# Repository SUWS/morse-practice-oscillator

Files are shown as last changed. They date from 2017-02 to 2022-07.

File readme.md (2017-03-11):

# Morse Code Practice oscillator

This contains the hardware and firmware designs for a morse code practice oscillator.

## Features

* 9v Battery or 12vDC powered
* Headphone or internal speaker output
* Adjustable Tone and Volume
* Support for paddle keys with variable speed and weight
* Capacitive iambic key unit included on PCB

## Sources and links

* Audio path based on designs by [Forrest Cook (WB0RIO)](http://www.solorb.com/elect/hamcirc/sidetone/)
* Capacitive Iambic key uses circuit from [John Parfrey (M0UKD)](https://m0ukd.com/homebrew/capacitive-cw-touch-key-circuits/)
* Project uses CC By icons from Dave Gandy (power icon (also remixed to make the dial and jack labels)) and Hanan (headphone icon)

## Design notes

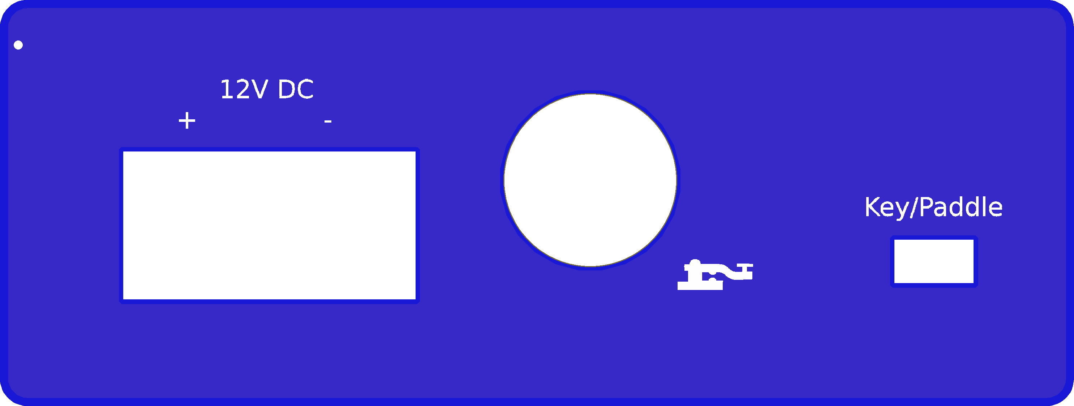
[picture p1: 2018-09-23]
Mechanicial/Sounder/textures/sounder_rear_pp_panel_r2.0_rear.png

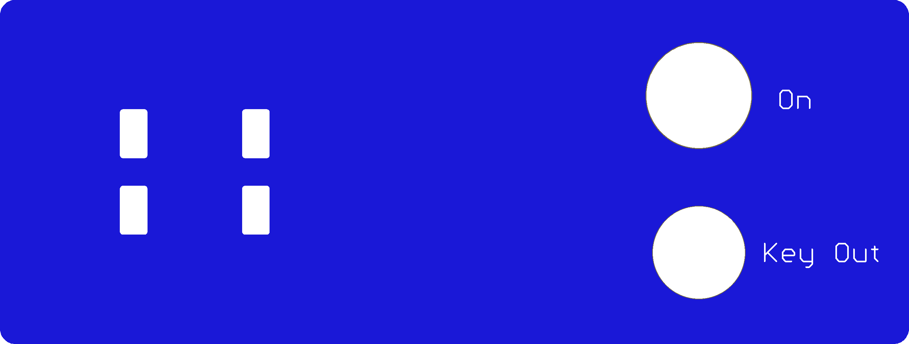
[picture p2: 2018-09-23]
Mechanicial/Key/textures/key_PCB_r1.0_front.png

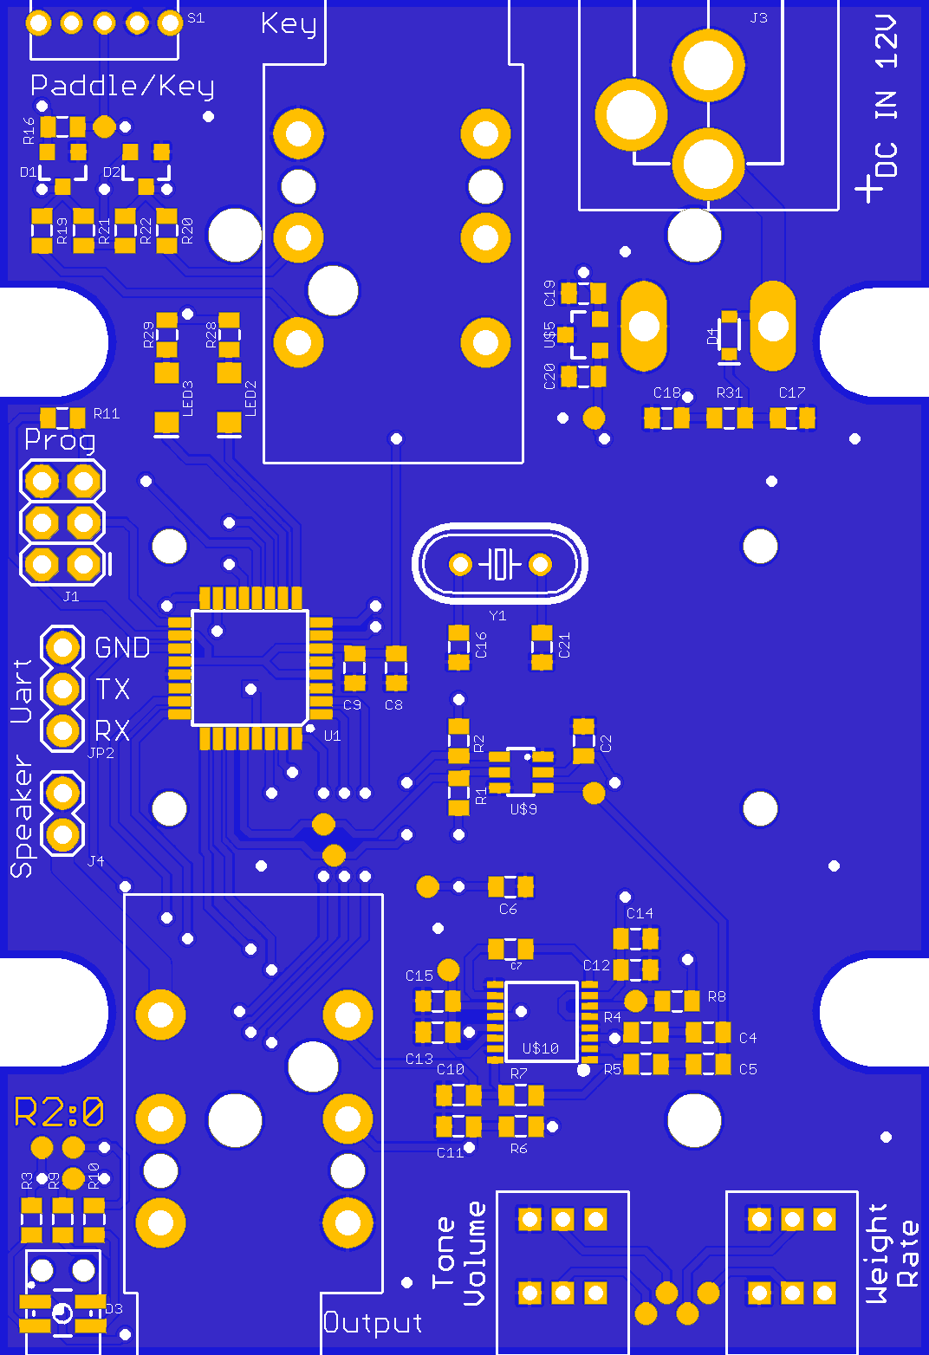
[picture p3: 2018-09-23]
Mechanicial/Sounder/textures/sounder_PCB_r2.0_top.png

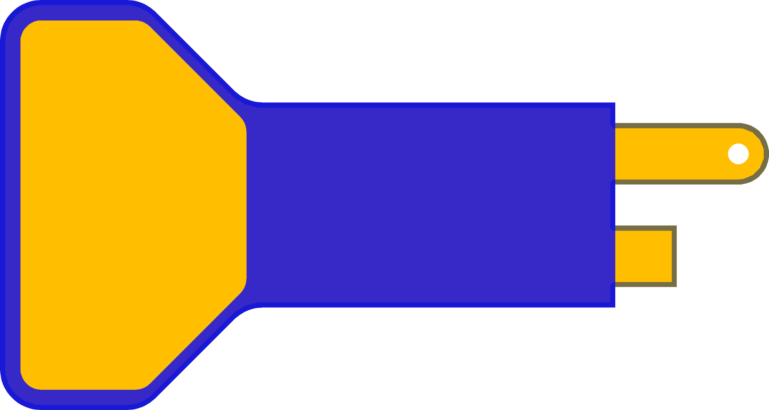
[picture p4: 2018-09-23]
Mechanicial/Key/textures/key_key_r1.0_outer.png

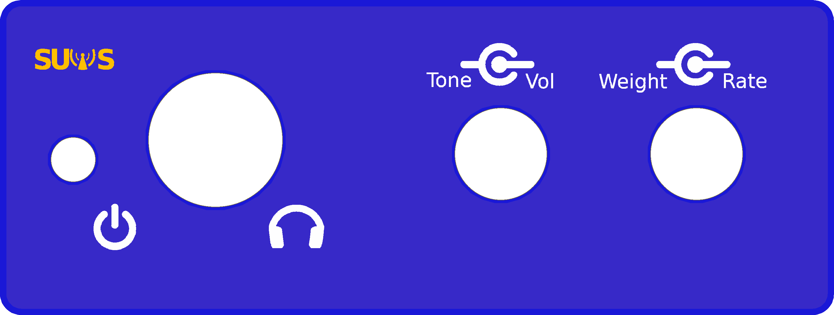
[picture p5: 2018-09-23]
Mechanicial/Sounder/textures/sounder_front_panel_r2.0_front.png

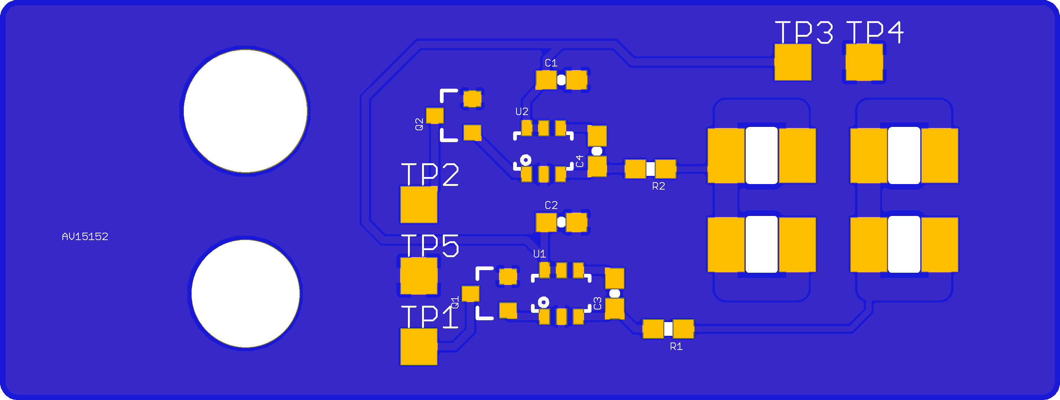
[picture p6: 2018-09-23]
Mechanicial/Key/textures/key_PCB_r1.0_back.png

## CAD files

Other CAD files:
Mechanicial/Key.ipt
Mechanicial/Key/1MS2.ipt
Mechanicial/Key/AA.ipt
Mechanicial/Key/AAHolder.ipt
Mechanicial/Key/Imported Components/1593P Battery Cover/1593P Battery Cover.ipt
Mechanicial/Key/Imported Components/1593P Bottom/1593P Bottom.ipt
Mechanicial/Key/Imported Components/1593P Top/1593P Top.ipt
Mechanicial/Key/Imported Components/1593P-Q Flat endplate/1593P-Q Flat endplate.ipt
Mechanicial/Key/KeyerFrontIambic.iam
Mechanicial/Key/KeyerFront_Iambic.ipt
Mechanicial/Key/KeyerPaddle.ipt
Mechanicial/Key/MJ-074N.ipt
Mechanicial/Key/TouchKeyer.iam
Mechanicial/Key/TouchKeyer/AIP/Cable and Harness/TouchKeyer.Harness1.iam
Mechanicial/Key/TouchKeyer/AIP/Cable and Harness/TouchKeyer.Harness1.ipt
Mechanicial/Set.iam
Mechanicial/Sounder/Imported Components/1593L BOTTOM/1593L BOTTOM.ipt
Mechanicial/Sounder/Imported Components/1593L Endplate/1593L Endplate.ipt
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

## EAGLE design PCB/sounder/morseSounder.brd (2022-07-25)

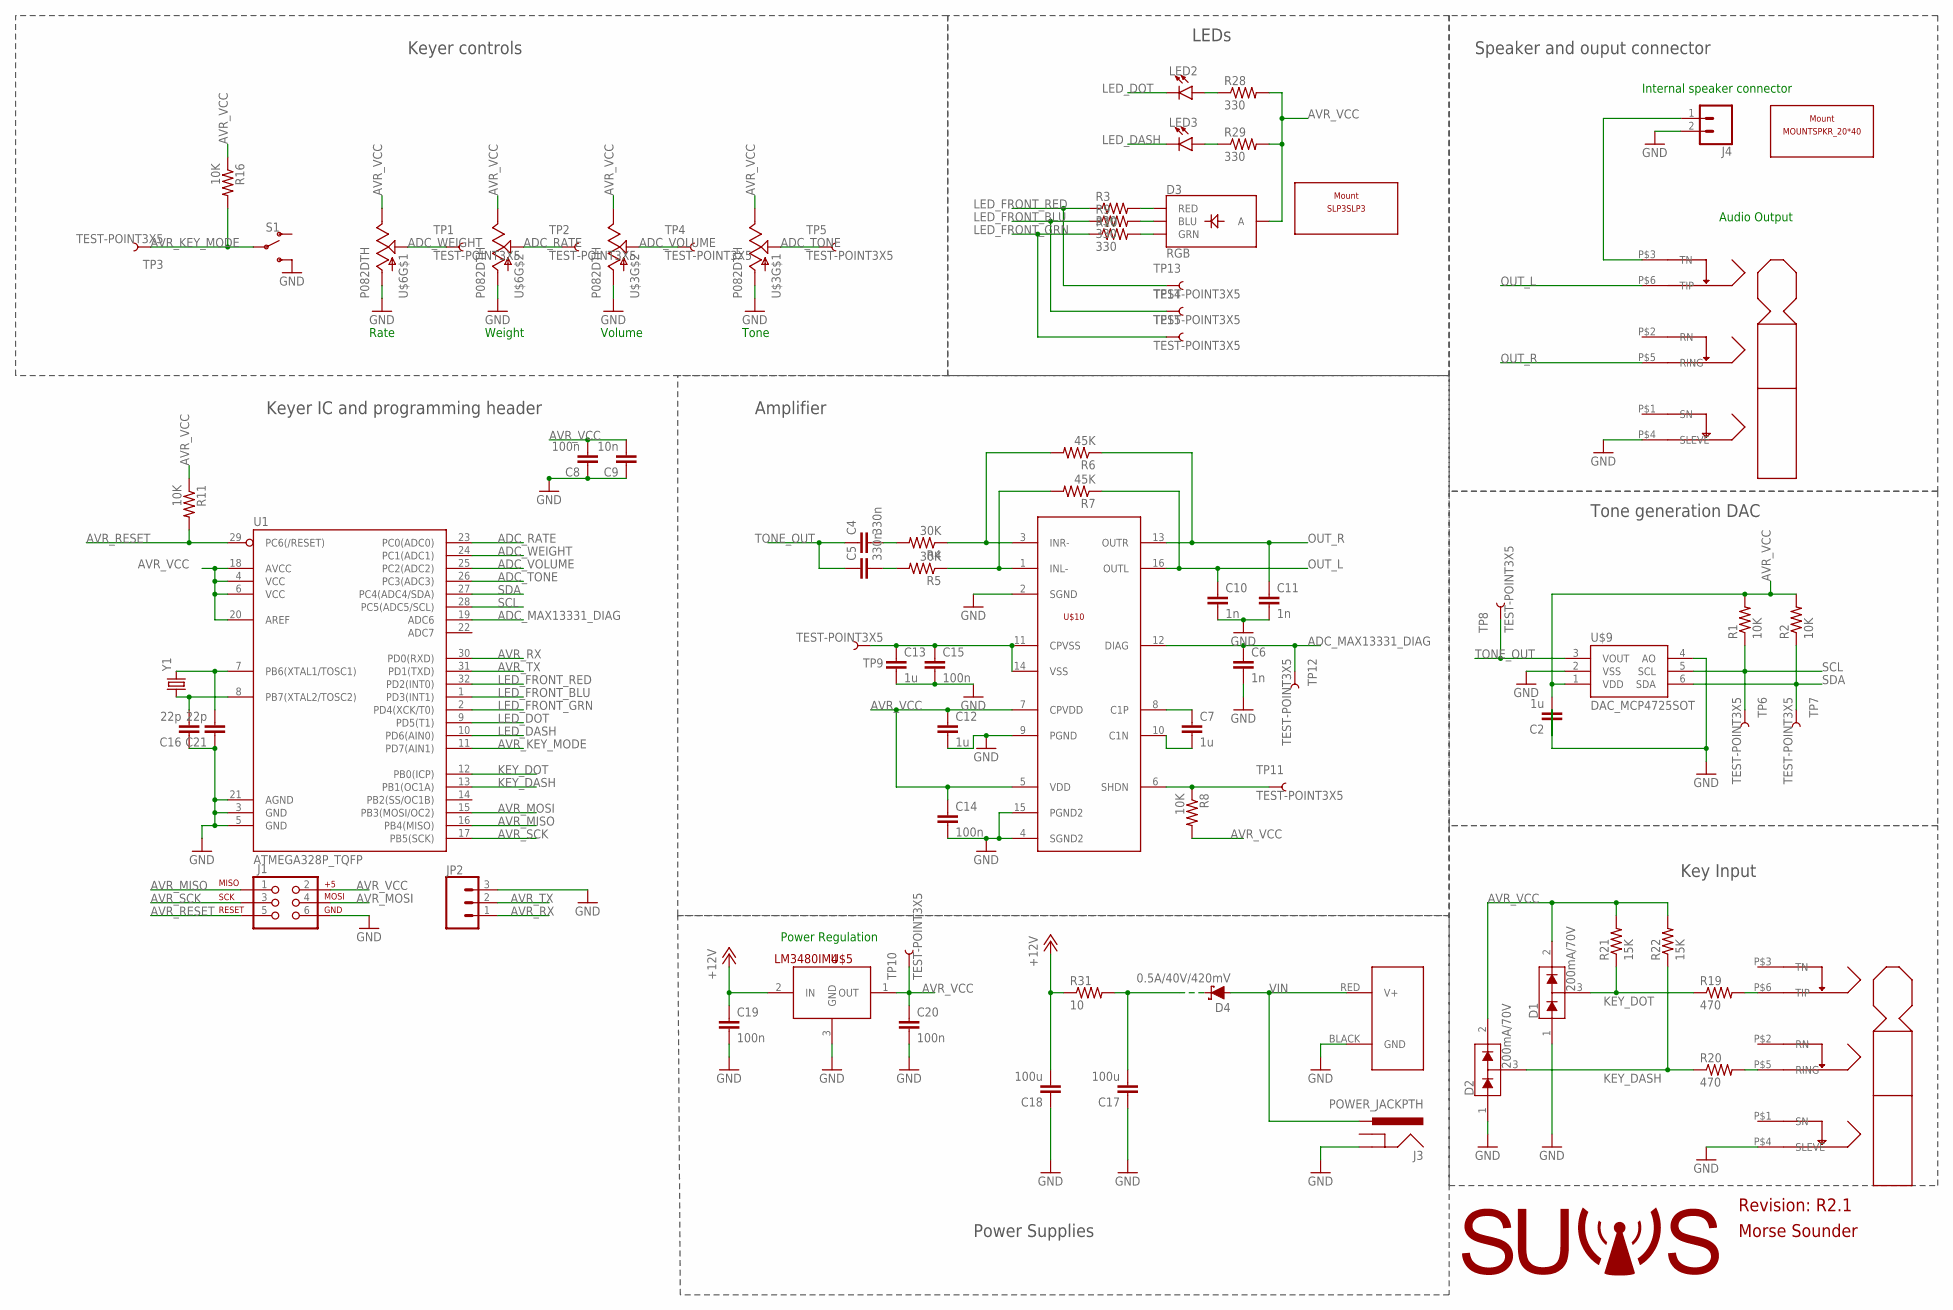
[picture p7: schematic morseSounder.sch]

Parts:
C2, C7, C12, C13: 1u; 0805
C4, C5: 330n; 0805
C6, C10, C11: 1n; 0805
C8, C14, C15, C19, C20: 100n; 0805
C9: 10n; 0805
C16, C21: 22p; 0805
C17, C18: 100u; 0805
D1, D2: 200mA/70V; SOT23-3
D3: RGB; P-LCC-4-3
D4: 0.5A/40V/420mV; SOD-323
J1: AVR_SPI_PRG_6PTH; 2X3
J2: POWERPOLE_POWER25A_HORIZONTAL_G2; POWERPOLE_PAIR_25A_HORIZ_G2
J3: POWER_JACKPTH; POWER_JACK_PTH
J4: CONN_02; 1X02
JP2: CONN_03; 1X03
LED2, LED3: LED-RED1206; LED-1206
R1, R2, R8, R11, R16: 10K; 0805
R3, R9, R10, R28, R29: 330; 0805
R4, R5: 30K; 0805
R6, R7: 45K; 0805
R19, R20: 470; 0805
R21, R22: 15K; 0805
R31: 10; 0805
S1: SWITCH-SPDTTE-1825232-1; TE-1825232-1
TP1, TP2, TP3, TP4, TP5, TP6, TP7, TP8, TP9, TP10, TP11, TP12, TP13, TP14, TP15: TEST-POINT3X5; PAD.03X.05
U1: ATMEGA328P_TQFP; TQFP32-08
U$1, U$2: NRJ6HH
U$3, U$6: P082DTH; P082D
U$4: MOUNTSPKR_20*40; SKR_MNT
U$5: LM3480IM4; SOT23-3
U$7: LOGO_SUWSLOGO_LARGE; LOGO_SUWS
U$8: SLP3SLP3; SLP-3
U$9: DAC_MCP4725SOT; SOT23-6
U$10: MAX13331; SSOP16
Y1: CRYSTALHC49UV; HC49U-V

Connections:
+12V: C18.2, C19.1, R31.1, U$5.2 (IN)
ADC_MAX13331_DIAG: C6.1, TP12.P$1, U1.19 (ADC6), U$10.12 (DIAG)
ADC_RATE: TP2.P$1, U1.23 (PC0(ADC0)), U$6.R2 (S)
ADC_TONE: TP5.P$1, U1.26 (PC3(ADC3)), U$3.F2 (S)
ADC_VOLUME: TP4.P$1, U1.25 (PC2(ADC2)), U$3.R2 (S)
ADC_WEIGHT: TP1.P$1, U1.24 (PC1(ADC1)), U$6.F2 (S)
AVR_KEY_MODE: R16.2, S1.2, TP3.P$1, U1.11 (PD7(AIN1))
AVR_MISO: J1.1, U1.16 (PB4(MISO))
AVR_MOSI: J1.4, U1.15 (PB3(MOSI/OC2))
AVR_RESET: J1.5, R11.2, U1.29 (PC6(/RESET))
AVR_RX: JP2.1, U1.30 (PD0(RXD))
AVR_SCK: J1.3, U1.17 (PB5(SCK))
AVR_TX: JP2.2, U1.31 (PD1(TXD))
AVR_VCC: C2.2, C8.2, C9.2, C12.1, C14.1, C20.1, D1.2 (C2), D2.2 (C2), D3.1 (A), J1.2, R1.2, R2.2, R8.2, R11.1, R16.1, R21.2, R22.2, R28.2, R29.2, TP10.P$1, U1.4 (VCC), U1.6 (VCC), U1.18 (AVCC), U1.20 (AREF), U$3.F3 (E), U$3.R3 (E), U$5.1 (OUT), U$6.F3 (E), U$6.R3 (E), U$9.1 (VDD), U$10.5 (VDD), U$10.7 (CPVDD)
GND: C2.1, C6.2, C8.1, C9.1, C10.2, C11.2, C12.2, C13.2, C14.2, C15.2, C16.1, C17.1, C18.1, C19.2, C20.2, C21.1, D1.1 (A1), D2.1 (A1), J1.6, J2.BLACK (GND), J3.GND, J4.2, JP2.3, S1.3 (S), U1.3 (GND), U1.5 (GND), U1.21 (AGND), U$1.P$4 (SLEVE), U$2.P$4 (SLEVE), U$3.F1 (A), U$3.R1 (A), U$5.3 (GND), U$6.F1 (A), U$6.R1 (A), U$9.2 (VSS), U$9.4 (AO), U$10.2 (SGND), U$10.4 (SGND2), U$10.9 (PGND), U$10.15 (PGND2)
KEY_DASH: D2.3 (COM), R20.1, R22.1, U1.13 (PB1(OC1A))
KEY_DOT: D1.3 (COM), R19.1, R21.1, U1.12 (PB0(ICP))
LED_DASH: LED3.C, U1.10 (PD6(AIN0))
LED_DOT: LED2.C, U1.9 (PD5(T1))
LED_FRONT_BLU: R9.1, TP14.P$1, U1.1 (PD3(INT1))
LED_FRONT_GRN: R10.1, TP15.P$1, U1.2 (PD4(XCK/T0))
LED_FRONT_RED: R3.1, TP13.P$1, U1.32 (PD2(INT0))
unnamed: C21.2, U1.7 (PB6(XTAL1/TOSC1)), Y1.2
unnamed: C16.2, U1.8 (PB7(XTAL2/TOSC2)), Y1.1
unnamed: D3.3 (GRN), R10.2
unnamed: C17.2, D4.C, R31.2
unnamed: C4.2, R4.2
unnamed: C5.2, R5.2
unnamed: R4.1, R6.2, U$10.3 (INR-)
unnamed: R5.1, R7.2, U$10.1 (INL-)
unnamed: R20.2, U$1.P$5 (RING)
unnamed: D3.4 (BLU), R9.2
unnamed: C7.1, U$10.8 (C1P)
unnamed: C7.2, U$10.10 (C1N)
unnamed: R19.2, U$1.P$6 (TIP)
unnamed: D3.2 (RED), R3.2
unnamed: R8.1, TP11.P$1, U$10.6 (SHDN)
unnamed: C13.1, C15.1, TP9.P$1, U$10.11 (CPVSS), U$10.14 (VSS)
unnamed: J4.1, U$2.P$3 (TN)
unnamed: LED3.A, R29.1
unnamed: LED2.A, R28.1
OUT_L: C10.1, R7.1, U$2.P$6 (TIP), U$10.16 (OUTL)
OUT_R: C11.1, R6.1, U$2.P$5 (RING), U$10.13 (OUTR)
SCL: R1.1, TP6.P$1, U1.28 (PC5(ADC5/SCL)), U$9.5 (SCL)
SDA: R2.1, TP7.P$1, U1.27 (PC4(ADC4/SDA)), U$9.6 (SDA)
TONE_OUT: C4.1, C5.1, TP8.P$1, U$9.3 (VOUT)
VIN: D4.A, J2.RED (V+), J3.PWR

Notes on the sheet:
Audio Output
Internal speaker connector
Rate
Weight
Keyer controls
Keyer IC and programming header
Power Regulation
Power Supplies
Key Input
Volume
Tone
LEDs
Tone generation DAC
Amplifier
Speaker and ouput connector
Revision: R2.1
Morse Sounder

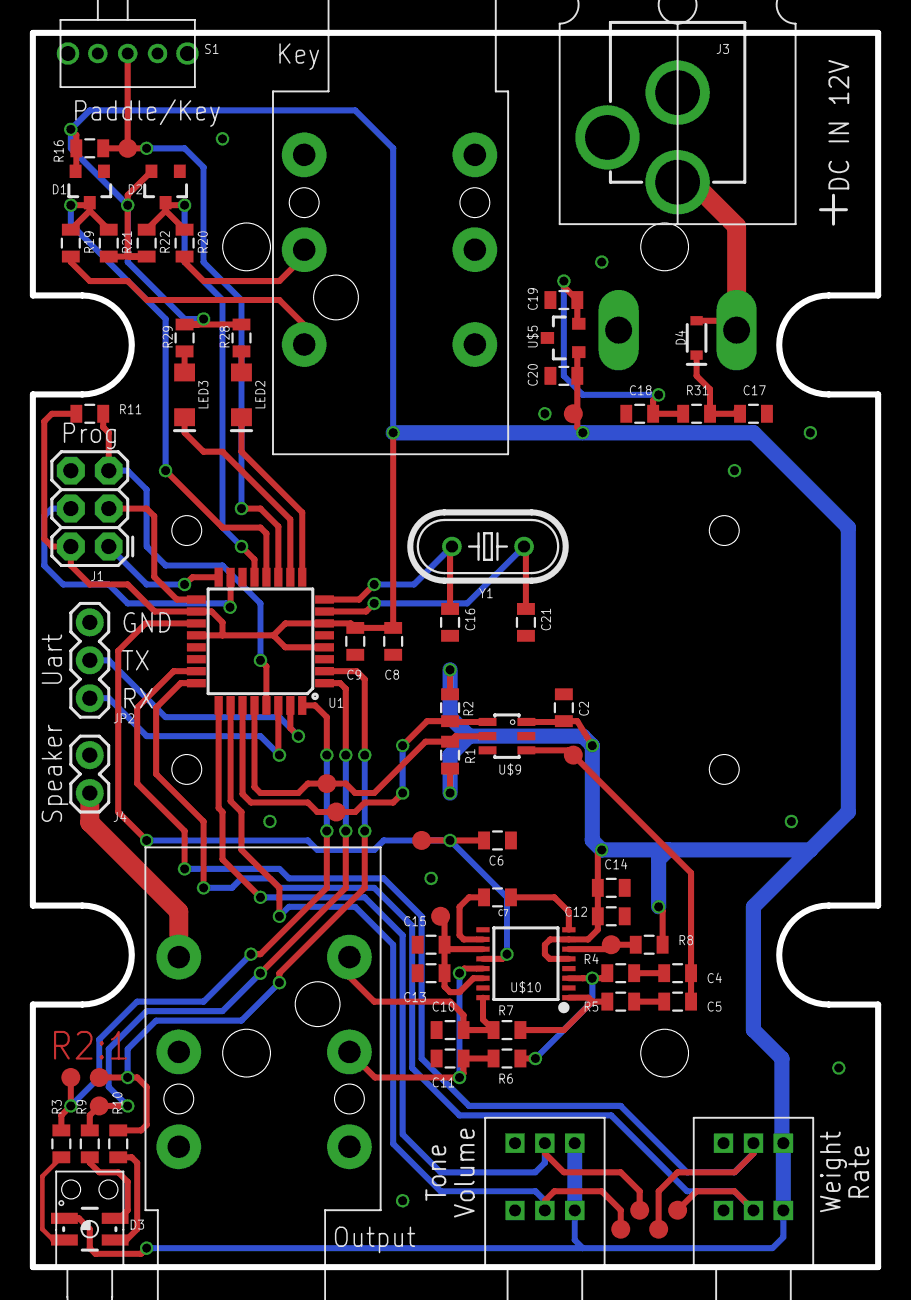
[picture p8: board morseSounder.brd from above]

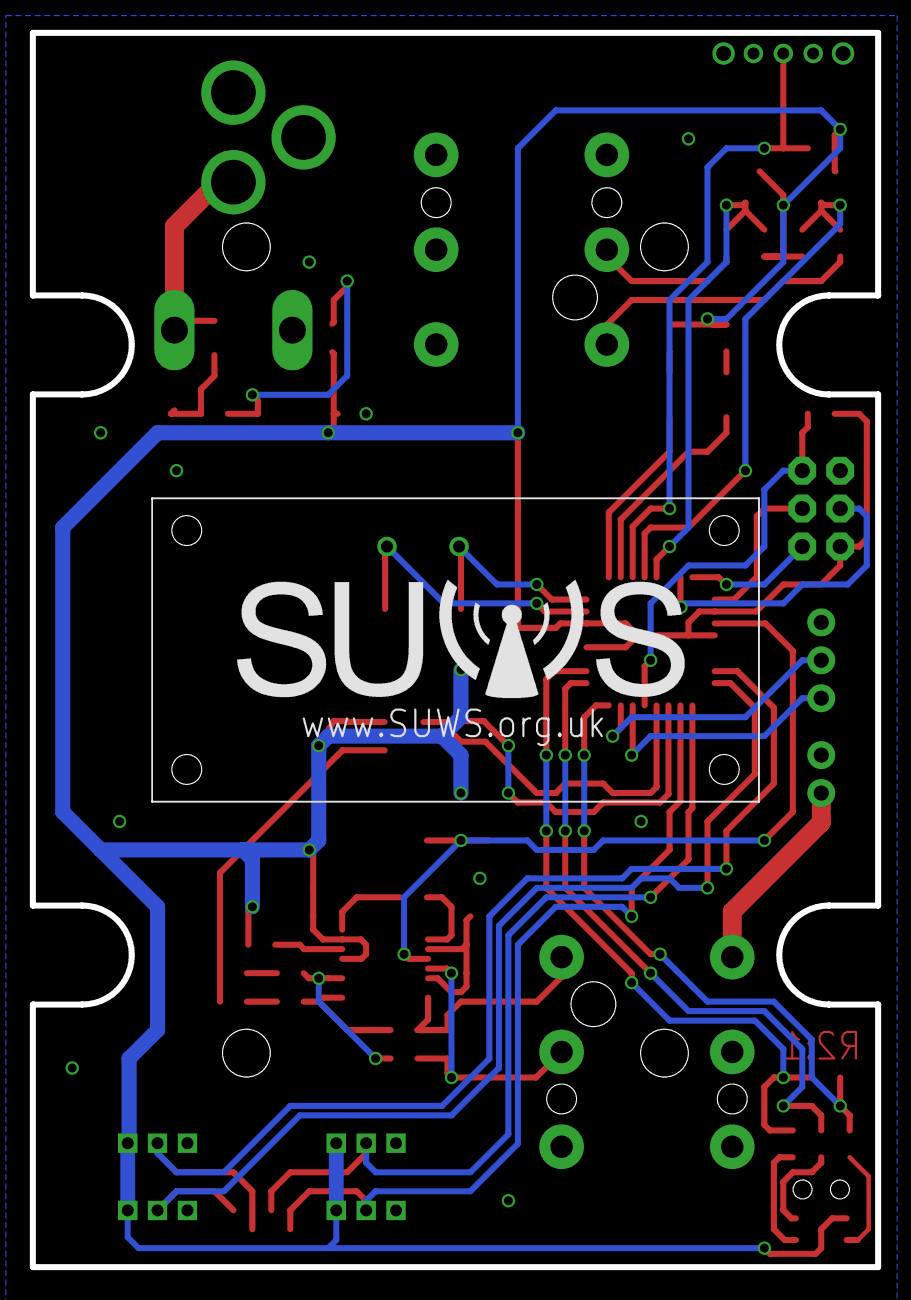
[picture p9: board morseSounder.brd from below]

Board: 2 copper layers, 56.6 x 82.7 mm, 77 parts (2 on the bottom side), 47 nets.

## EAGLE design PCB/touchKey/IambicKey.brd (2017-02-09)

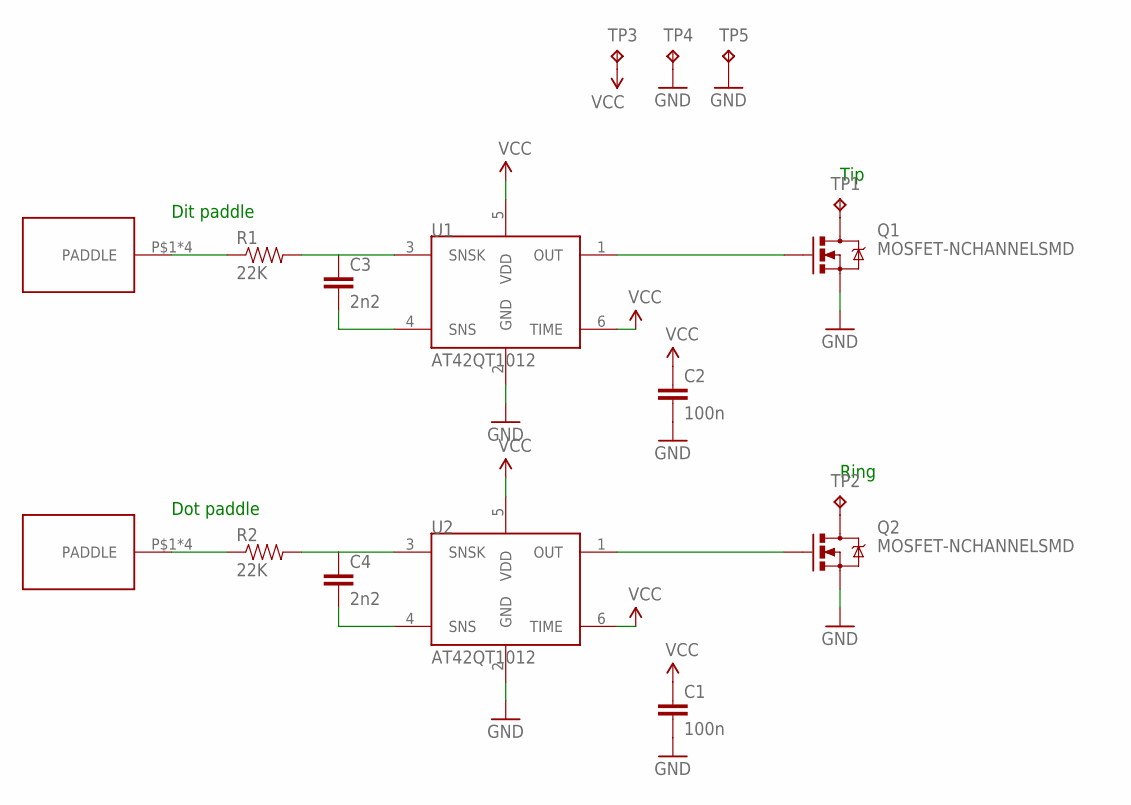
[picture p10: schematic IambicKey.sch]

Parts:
C1, C2: 100n; 0603-CAP
C3, C4: 2n2; 0603-CAP
Q1, Q2: MOSFET-NCHANNELSMD; SOT23-3
R1, R2: 22K; 0603-RES
TP1, TP2, TP3, TP4, TP5: TPTP20SQ; TP20SQ
U1, U2: AT42QT1012; SOT-23-6
U$1, U$2: PADDLE

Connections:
GND: C1.2, C2.2, Q1.2 (S), Q2.2 (S), TP4.TP, TP5.TP, U1.2 (GND), U2.2 (GND)
unnamed: Q1.1 (G), U1.1 (OUT)
unnamed: Q2.1 (G), U2.1 (OUT)
unnamed: C3.2, U1.4 (SNS)
unnamed: C3.1, R1.2, U1.3 (SNSK)
unnamed: R1.1, U$1.P$1, U$1.P$2, U$1.P$3, U$1.P$4
unnamed: C4.2, U2.4 (SNS)
unnamed: C4.1, R2.2, U2.3 (SNSK)
unnamed: R2.1, U$2.P$1, U$2.P$2, U$2.P$3, U$2.P$4
unnamed: Q1.3 (D), TP1.TP
unnamed: Q2.3 (D), TP2.TP
VCC: C1.1, C2.1, TP3.TP, U1.5 (VDD), U1.6 (TIME), U2.5 (VDD), U2.6 (TIME)

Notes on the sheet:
Dit paddle
Dot paddle
Tip
Ring

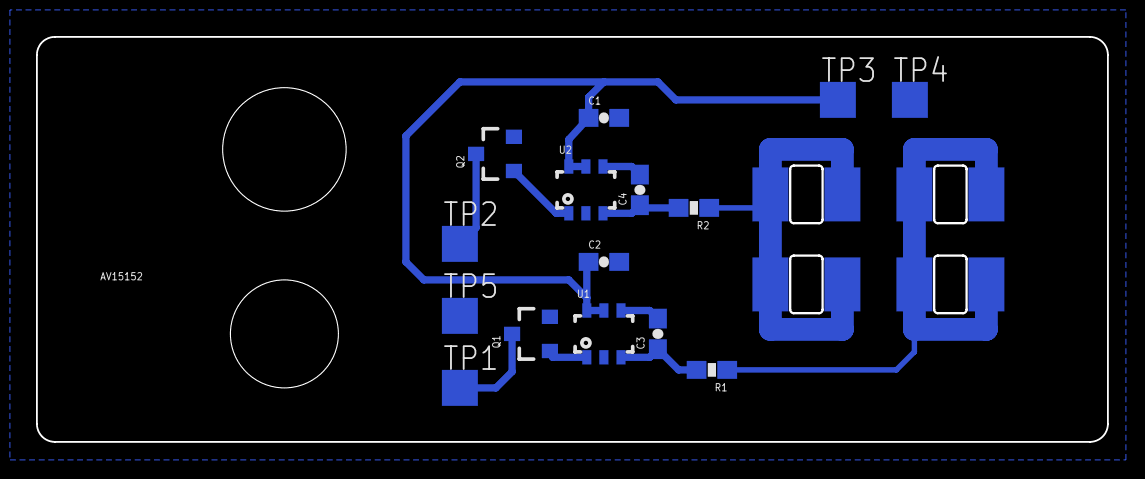
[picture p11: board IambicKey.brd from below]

Board: 2 copper layers, 59.5 x 22.5 mm, 17 parts (15 on the bottom side), 12 nets.

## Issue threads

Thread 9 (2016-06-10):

Test first sounder unit

Tyler-Ward, 2016-06-10:
Assemble and test the first unit and confirm correct operation

Tyler-Ward, 2018-07-07:
Rev2 sounder unit tested and functional

Closed 2018-07-07.

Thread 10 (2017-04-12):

Debug hardware issues with first sounder

Tyler-Ward, 2017-04-12:
Debug the following issues.
- [ ] clicking sounds on the output which corolate to fluxuations in the power supply when the AVR performed GIPO functions, not sure why this is as there is plenty of power supply filtering
- [ ] there was a lot of noise on the output not sure of the cause
- [ ] the final amplifier seemed to get very hot at times, not sure of the cause but suspect it is related to the volume
 - [ ] tone output seems quite a bit lower than expected.
- [x]  power LED resistor is a bit to large and as a result is quite dim

Tyler-Ward, 2017-09-18:
Replace Power LED resistor with 1K incorrectly had 22K on schematic

Tyler-Ward, 2018-07-07:
Replaced designs with rev 2 issues no longer present

Closed 2018-07-07.

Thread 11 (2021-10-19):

Wrong capacitor value for C3 and C4

Tyler-Ward, 2021-10-19:
C3 and C4 should be 1nf for a more reliable operation, the current 2.2nf value causes activation before the paddles are touched fairly often

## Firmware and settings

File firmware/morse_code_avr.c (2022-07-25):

/********************************************************************
 File Description:

 Contains main process for the morse sounder

********************************************************************/

#include <avr/io.h>
#include <string.h>
#include <stdio.h>

//Core definitions
#include "hardware.h"

//include delay.h after hardware.h due to F_CPU definition
#include <util/delay.h>

//core libraies
#include "uart.h"
#include "adc.h"
#include "i2c.h"
#include "MCP4725.h"
#include "led.h"
#include "tone_generator.h"
#include "keying.h"


int main(int argc, char const *argv[])
{
	ADCInit();
    UartInit();
    I2CInit();
    LEDInit();

    ToneInit();
    KeyingInit();

	// Setting PC2(dot) & PC3(dash) as digital inputs
	KEY_IN_PORT_DDR &= ~_BV(LED_DOT);
	KEY_IN_PORT_DDR &= ~_BV(LED_DASH);

	while(1)
	{
        //Check for slected mode
        if(((KEY_MODE_PORT_PIN >> KEY_MODE)&0x01)==1)
		{
			//Paddle key mode
			KeyingProcess();
			if(ToneEnabled())
			{
				LEDPowerSet(POWER_COLOUR_RED);
			}
			else
			{
				LEDPowerSet(POWER_COLOUR_BLUE);
			}
		}
		else
        {
			//Straight key mode
	        if(((KEY_IN_PORT_PIN >> KEY_STRAIGHT)&0x01)==1)
	        {
				LEDPowerSet(POWER_COLOUR_GREEN);
	            ToneStop();
	        }
	        else
	        {
				LEDPowerSet(POWER_COLOUR_RED);
	            if(!ToneEnabled())
	            {
	                ToneStart();
	            }
	        }
        }

        ADCProcess();

		//dot indicator LED
		if(!(KEY_IN_PORT_PIN & _BV(KEY_DOT)))
		      LEDDotOn();
		else
		      LEDDotOff();

		//dash indicator LED
		if(!(KEY_IN_PORT_PIN & _BV(KEY_DASH)))
		      LEDDashOn();
		else
		      LEDDashOff();

	}

	return 0;
}

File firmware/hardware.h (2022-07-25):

/********************************************************************
 File Description:

 Contains pin definitions and other hardware specific options
 Hardware definitions are for r2.0 sounder hardware

********************************************************************/


#ifndef HARDWARE_H_
#define HARDWARE_H_

#define F_CPU 16000000

/* INDICATOR LED ***************************************************/

#define INDICATOR_LED_PORT PORTD  //!< port register for indicator LED
#define INDICATOR_LED_PIN PIND    //!< pin register for indicator LED
#define INDICATOR_LED_DDR DDRD    //!< data direction register for indicator led

#define INDICATOR_LED_RED PD2     //!< indicator LED red
#define INDICATOR_LED_BLUE PD3     //!< indicator LED blue
#define INDICATOR_LED_GREEN PD4     //!< indicator LED green

/* KEY INPUT *******************************************************/

#define KEY_IN_PORT PORTB         //!< port register for Key input
#define KEY_IN_PORT_PIN PINB      //!< pin register for key input
#define KEY_IN_PORT_DDR DDRB      //!< data direction register for key input

#define KEY_DOT PB0               //!< dot paddle connection also straight key input
#define KEY_STRAIGHT PB0          //!< straight key input
#define KEY_DASH PB1              //!< dash paddle connection

/* KEY INPUT LEDS **************************************************/

#define KEY_LED_PORT PORTD        //!< port register for key led indicators
#define KEY_LED_PORT_PIN PIND     //!< pin register for key led indicators
#define KEY_LED_PORT_DDR DDRD     //!< data direction register for key led indicators

#define LED_DOT PD5               //!< dot indicator LED
#define LED_DASH PD6              //!< dash indicator LED

/* SETTING INPUTS **************************************************/

#define ADC_SETTINGS_PORT PORTC   //!< port register for potentiometer input
#define ADC_SETTINGS_PORT_PIN PINC //!< pin register for potentiometer input
#define ADC_SETTINGS_PORT_DDR DDRC  //!< data direction register for potentiometer input

#define ADC_RATE PC0              //!< rate setting input
#define ADC_WEIGHT PC1            //!< weight setting input
#define ADC_VOLUME PC2            //!< weight setting input
#define ADC_TONE PC3              //!< rate setting input

#define KEY_MODE_PORT PORTD       //!< port register for key mode
#define KEY_MODE_PORT_PIN PIND    //!< pin register for key mode
#define KEY_MODE_PORT_DDR DDRD    //!< data direction register for key mode

#define KEY_MODE PD7              //!< key mode input

/* DEBUG UART INTERFACE ********************************************/

#define I2C_PORT PORTD            //!< port register for I2C
#define I2C_PIN PIND              //!< pin register for I2C
#define I2C_DDR DDRD              //!< data direction register for I2C

#define I2C_SDA PC4              //!< I2C SDA pin
#define I2C_SCL PC5              //!< I2C SCL pin

/* AMP DEBUG *******************************************************/

#define AMP_DEBUG_PORT PORTC      //!< port register for amplifier debug
#define AMP_DEBUG_PIN PINC        //!< pin register for amplifier debug
#define AMP_DEBUG_DDR DDRC        //!< data direction register for amplifier debug

#define AMP_DEBUG PC6             //!< amplifier debug input

/* DEBUG UART INTERFACE ********************************************/

#define DEBUG_UART_PORT PORTD     //!< port register for debug uart
#define DEBUG_UART_PORT_PIN PIND  //!< pin register for debug uart
#define DEBUG_UART_PORT_DDR DDRD  //!< data direction register for debug uart

#define DEBUG_TX PD1              //!< debug uart transmit pin
#define DEBUG_RX PD0              //!< debug uart receive pin

#endif /* HARDWARE_H_ */

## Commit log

2016-05-29 Added initial schematic and ltspice simulations
    [morseSounder.sch]
2016-05-30 Added avr based keyer and key input stages
    [morseSounder.sch]
2016-05-30 Added power supply circuitry
    [morseSounder.sch]
2016-06-17 Added Touch keyer circuit and initial board
    [IambicKey.brd, IambicKey.sch, morseSounder.sch]
2016-12-24 optimized schematic components and added initial board file
    [morseSounder.brd, morseSounder.sch]
2017-02-09 Replaced most through hole components with SMD equivilents
    [IambicKey.brd, IambicKey.sch, morseSounder.brd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]
2017-02-16 Tidied up silk screen on PCB
    [morseSounder.brd]
2017-02-19 Added test points and cleaned up some silkscreen issues
    [morseSounder.brd, morseSounder.sch]
2017-02-21 * Removed the pair of unused opto-isolators. * Commenced tidying up the schematic. & Removal of 3rd opto-isolator may prove tricky...
    [morseSounder.brd, morseSounder.sch]
2017-02-22 Add files via upload
    This is the firmware embedded c code running on the avr chip, still havnt done the key_mode configuration yet will do soon and still need to do a final check if the other pin features have been met o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
2017-02-23 * Removed opto-isolator driving the amplifier. Swapped to a high side MOSFET driver. Note this makes the micro mandatory. * Added input protection for the key.
    [morseSounder.brd, morseSounder.sch]
2017-02-23 * Oops! Power reverse protection diode should protect both power inputs!
    [morseSounder.brd, morseSounder.sch]
2017-02-25 Routed rest of PCB
    Altered pin placement on AVR
    Added additional protection to key input
    Separated LEDS from key input
    [morseSounder.brd, morseSounder.sch]
2017-02-25 Added some decoupling capacitors and tidied silk screen
    [morseSounder.brd, morseSounder.sch]
2017-03-05 Swapped power LED for right angle version
    [morseSounder.brd, morseSounder.sch]
2017-03-05 moved PCB files
    [morseSounder.brd, morseSounder.sch]
2017-03-05 Moved touch key PCB files
    [IambicKey.brd, IambicKey.sch]
2017-03-05 Created PCB sub gitignore and removed PCB ignores from main gitignore
2017-03-05 Added initial case panel designs
    [back_pp.brd, front.brd]
2017-03-05 Added back panel with jack power option
    [back_jack.brd]
2017-03-05 Added panellised R1:0 PCBs
    [pannel 1.brd, pannel 2.brd]
2017-03-11 Refined designs for PCB order
    [pannel 1.brd, pannel 2.brd]
2017-03-23 Made pin chages to the firmware code
    and changed the adc read function a bit
    - still need to verify it by tyler
    - still need to test the code using a test circuit on my ilmatto (need
    to discuss it with tyler)
    - Need to implement adc keymode
2018-03-26 Rebuilt audio circuit to use a synthesised digital source rather than a tone generator.
    Other improvements.
    RGB power light/status indicator.
    Better amplifier circuit.
    [morseSounder.brd, morseSounder.sch]
2018-03-26 Modified front panel for new light pipe design
    [front.brd]
2018-03-26 Merged new board and front panel onto single panel for manufacture
    [pannel 1.brd]
2018-04-30 Added hardware.h for r2.0
    Also replaced main function with basic test program.
    [hardware.h, morse_code_avr.c]
2018-05-01 Updated makefile for chip used on board
2018-05-01 Added more test code to test the ADC and digital inputs.
    Also added basic uart printing for debug output.
2018-05-05 Moved uart code to its own file
2018-05-05 moved ADC code out of main file
2018-05-05 Moved MCP4625 and i2c code to seperate files
2018-05-05 Added a tone generator function which creates the required tones.
    Also added a file for LED control and moved the I2c writing code for the
    MCP4725 to the I2C file.
2018-05-05 fixed compiler errors and warnings
    [i2c.c, tone_generator.c]
2018-05-05 Moved I2C to an interrupt based system.
2018-05-06 Tone generation is now entireley interrupt driven
2018-09-23 Added mechanical design files for sounder
    [1593L BOTTOM.ipt, 1593L Endplate.ipt, 1593L Top.ipt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]
2018-09-23 Added mechanical deisgn files for key
    [1593P Battery Cover.ipt, 1593P Bottom.ipt, 1593P Top.ipt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]
2018-09-23 Fixed Pinout of DAC chip
    [morseSounder.brd, morseSounder.sch]
2018-09-23 Added document frame to the Sounder Schematic
    [morseSounder.sch]
2018-09-29 bumped version number on boards and updated panel 1 with new design
    [morseSounder.brd, pannel 1.brd]
2018-09-29 Fixed mode switch being back to front
    [adc.c, morse_code_avr.c]
2019-03-18 Added red led indication on tone
2022-07-25 Flip weight and rate controls to match front pannel
    [morseSounder.brd, morseSounder.sch]
2022-07-25 Move power LED control to main file
2022-07-25 Update component values to reduce volume and remove output distortion
    [morseSounder.sch]
2022-07-25 Ensure ADC returns to zero after tone output
    Also adjust volume curve to provide more low volume options.

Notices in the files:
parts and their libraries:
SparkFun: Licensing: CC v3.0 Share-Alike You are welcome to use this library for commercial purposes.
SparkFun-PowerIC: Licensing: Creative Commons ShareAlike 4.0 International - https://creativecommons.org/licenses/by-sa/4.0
